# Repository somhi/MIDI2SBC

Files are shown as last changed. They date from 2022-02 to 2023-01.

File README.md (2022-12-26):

# MIDI I2S SBC Pmod Edge Interface

STATUS (26/12/22): Finished gerber files for v1.10. See changelog for updates from v0.7 to v1.1

STATUS (24/03/22): Finished most of testing satisfactorily. 

STATUS (24/03/22): received pcbs (16/03/22) and started testing.  

STATUS (01/03/22): sent v0.70 to manufacturing at JLCPCB

### Intro

This board was born as an addon for [NeptUNO](https://github.com/neptuno-fpga/Main_nepUNO/wiki) FPGA platform (although it can be linked to other FPGAs) for interfacing with a MIDI synthesizer (mt32-pi), DAC I2S, single board computers (or microcontrollers) and pmod peripherals.

This is my first PCB design attempt. 

Project has been developed with KiCAD 6.0.

This design is based on the Eagle design of the RTC+I2S+PIzero Addon by [Antonio Villena](https://www.antoniovillena.es/store/). I have to thank Antonio for his help.

### Flow diagram

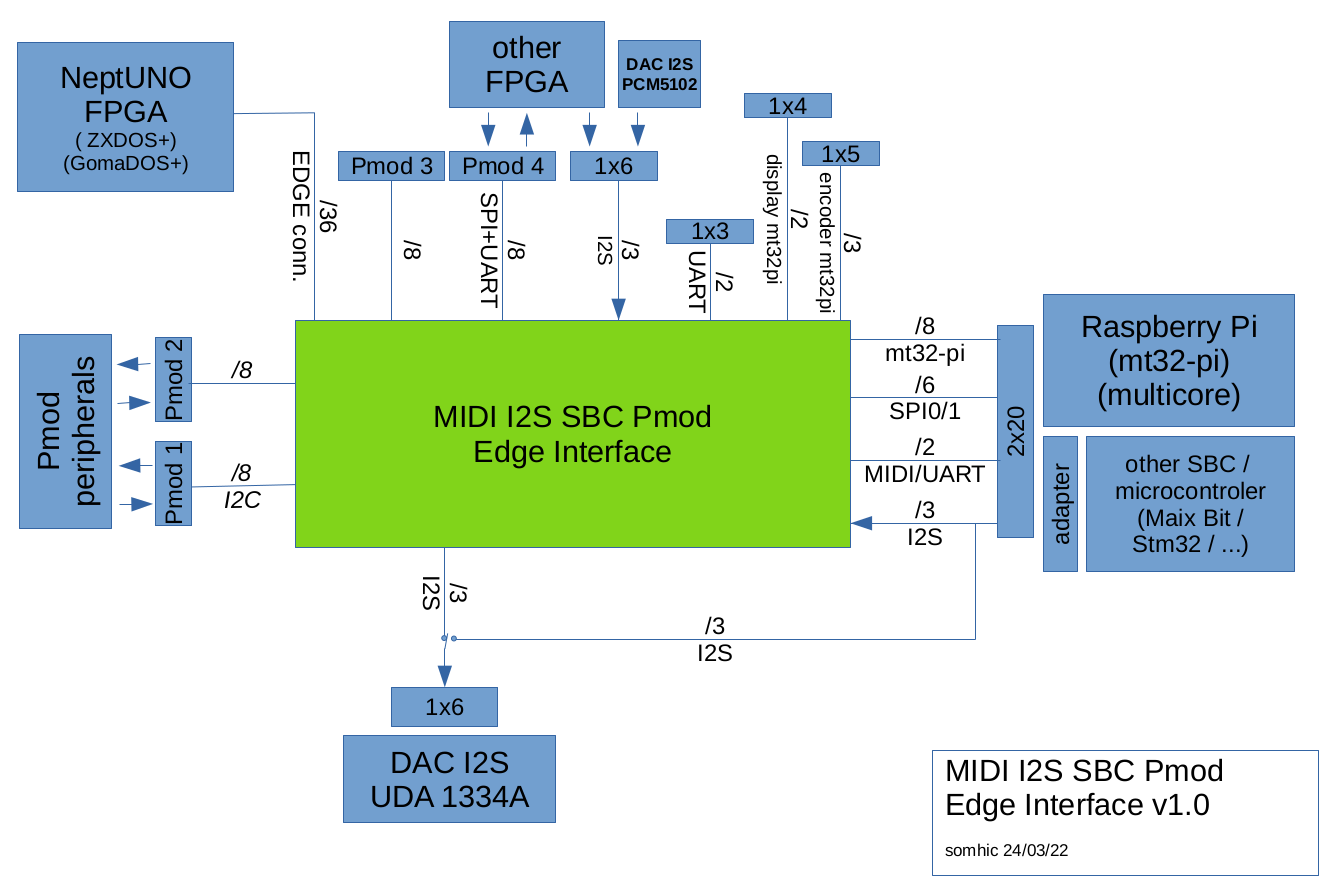
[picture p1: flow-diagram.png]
flow-diagram


### **Schematic**

[addon-edge-rpi-i2s-pmod.pdf](addon-edge-rpi-i2s-pmod.pdf)

### **Features**

* MIDI synthesizer: [mt32-pi](https://github.com/dwhinham/mt32-pi) 
  
  * Play MIDI sounds from FPGA core through an I2S DAC
  * It is possible to send mt32-pi I2S audio back to FPGA for mixing with other core audio and play it back through the I2S DAC
  * PCB includes footprints for an I2C OLED display, a rotative encoder and 2 buttons
  * Control mt32-pi through i2c pins (e.g. from MiSTer's OSD)
  
* DAC I2S: 
  
  * Play I2S audio sent from your FPGA (connected to Edge or Pmod 4)
  * Play I2S audio from Raspberry mt32-pi
  * PCB includes footprints for UDA 1334A and PCM5102A
  
* SBC / Micro-controller interface (Multicore)
  * Interface to FPGAs through Edge or Pmod 4 connectors
  * Interface signals: SPI (6 signals) and UART (Rx/Tx) 
  * PCB includes footprint for Raspberry Pi model B 40 pin connector. Other SBCs or microcontrollers can be interfaced through adapters (e.g. MAix BiT and STM32 adapters are available in [Atlas FPGA project](https://github.com/atlasfpga))
  * A SBC or uC could be used as a multicore device for the FPGA
  
* UART header connected to FPGA (Rx, Tx) (and Raspberry Pi also)

**Additional features for the Edge connector ** 

* Compatible platforms: NeptUNO, ZXDOS+ and GomaDOS+ from [Antonio Villena](https://www.antoniovillena.es/store/). 
  * NeptUNO base board is compatible with most of QMTech FPGAs
* PMODs 1 & 2 for double Pmod peripherals (like Hyperram, VGA, HDMI, ....)
  * Pmod 1 is connected to I2C lines of NeptUNO base board
  * Includes a 5V power supply header between Pmods  for broader compatibility
* PMODs 3 & 4  
  * Can be used as host or peripheral pmods (jumper JP5 enables output power). 
  * Includes a 5V power supply pin between Pmods  for broader compatibility
  * Notes:
    * Double Pmod for peripherals is only possible if not using mt32-pi or multicore options
    * Pmod 3 cannot be used with NeptUNO board cores usign SRAM

### 3D model

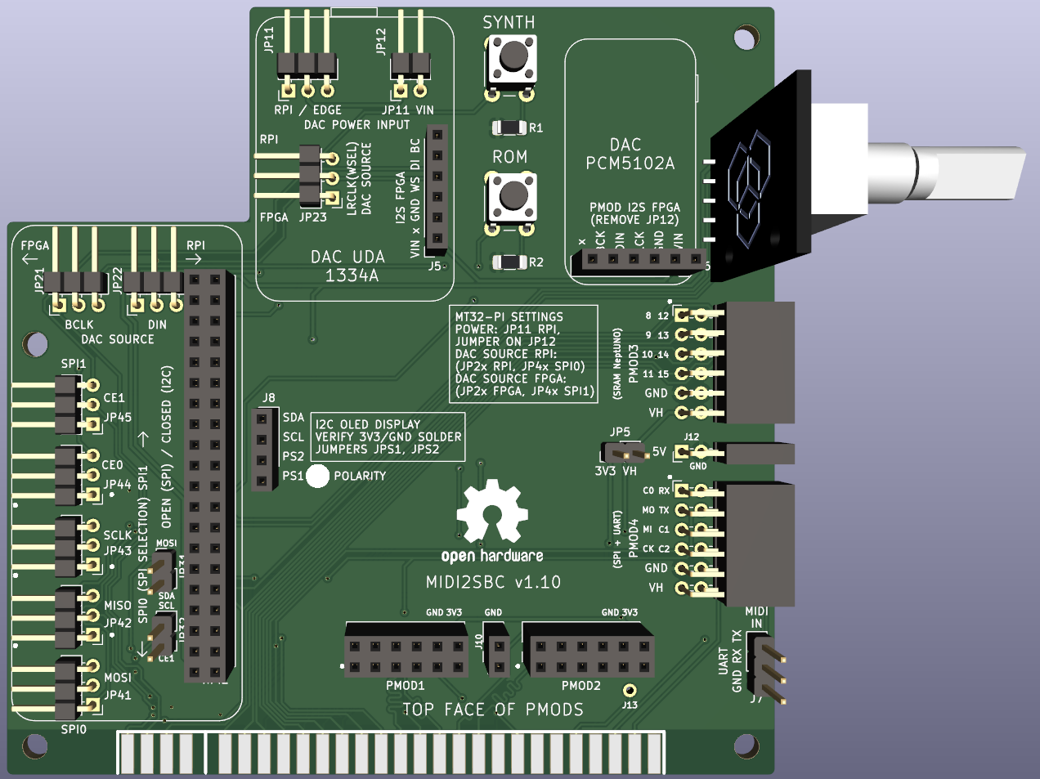
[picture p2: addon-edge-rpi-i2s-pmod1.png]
addon-edge-rpi-i2s-pmod1


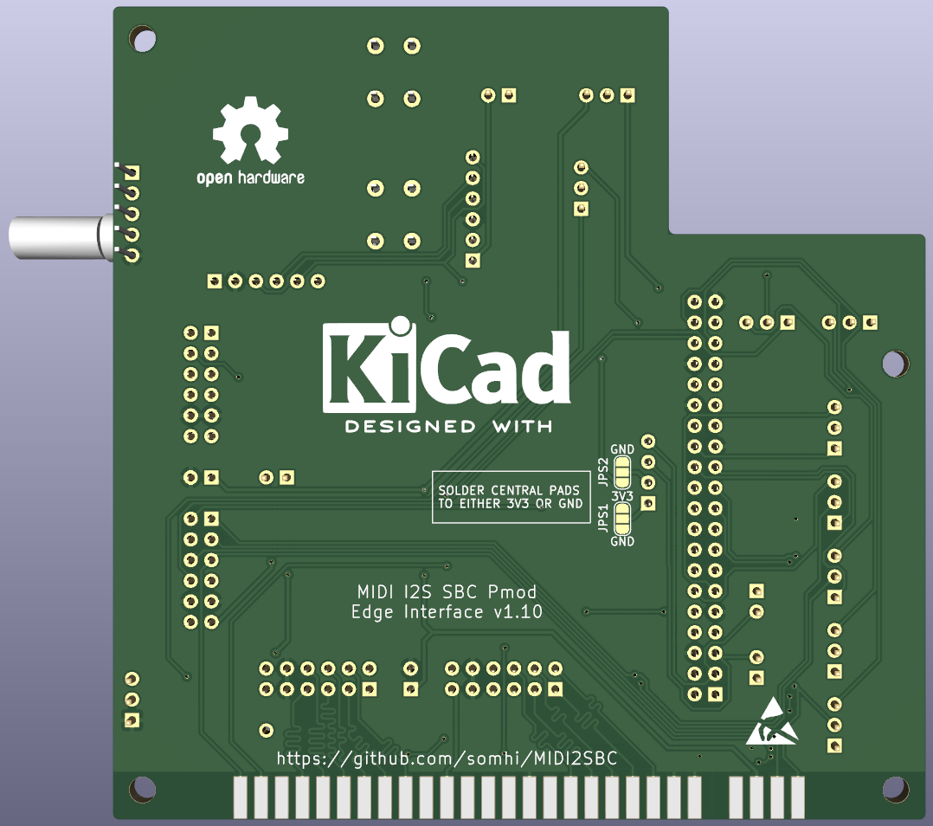
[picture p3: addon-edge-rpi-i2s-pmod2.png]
addon-edge-rpi-i2s-pmod2


### **Usage notes**

* It is recommended to power supply first the FPGA and thereafter the MISI2SBC addon
  
* DAC I2S 
  
  * Only one DAC (either UDA 1334A or PCM5102A) is intended to be used at the same time, although should be possible to run them simultaneously.
  * DAC input voltage can be selected by jumpers from Edge, Raspberry Pi or other FPGA
  * PCM5102A connector is compatible with a 6 pin Pmod if JP11 jumper is removed.
  
* SPI communication between Raspberry Pi and FPGA
  * SPI 0 or SPI 1 is available (selection by jumpers JP4x) 
  * External FPGAs are to be connected to Pmod4 (SPI + UART)

* mt32-pi synthesizer
  * Power supply: JP11 set to RPI and short JP12 with a jumper
  * DAC source from FPGA: SPI 1 should be selected when using mt32-pi (jumpers JP4x)
  * DAC source from RPi: No jumper or SPI 0 should be selected when using mt32-pi (jumpers JP4x)
  * External FPGAs are to be connected to Pmod I2S (PCM5102A) and MIDI In (UART) or Pmod4 (SPI + UART) for mixing.
  * MiSTer OSD i2c control: short jumpers JP31, JP32 and remove jumpers from JP41, JP45.

### **Jumpers / Switches selection**

The board has several jumpers for a broader usage with multiple configurations. Instead of right angle pin headers with jumpers is also possible to use 3 pin mini switches.

**Jumper types**

* 2 pin jumper is either shorted (jumper on) or disconnected (without jumper)

* 3 pin jumper is either on one side or the other always connecting the central pin

**Jumper selection**

* DAC I2S Power supply input source  

  * JP11:  RPI / EDGE   (3 pin jumper)
    * RPI (5V from Raspberry Pi)
    * EDGE (5V from Edge connector (NeptUNO FPGA))
  * JP12  (2 pin jumper)

    * Jumper shorting JP11 and VIN (5V from selection of JP11 jumper is applied to VIN)
    * Without jumper (DAC power input comes from any VIN pin (J4, J5 or J12 Vin itself))

* DAC I2S Audio Source (3 pin jumper)
  * DAC I2S connected to FPGA: I2S sound from MIDI synthesizer mt32-pi (MIDI_CLKBD, MIDI_WSBD, MIDI_DABD signals) is routed to the FPGA (where could be mixed with other core sounds) and the FPGA sends the I2S signals back to the DAC I2S (BCLK, WSEL, DIN signals).
    * JP21, JP22, JP23 jumper connected to the FPGA mark side
  * DAC I2S connected directly to the MIDI synthesizer (mt32-pi)
    * JP21, JP22, JP23   jumper connected to the RPI mark side

* SPI / I2C selection  (2 pin jumpers)

  * SPI selection: JP31 and JP32 open.
  * I2C selection: JP31 and JP32 closed (central pins of MOSI JP41 and CE1 JP45 are wired to the I2C bus connected to the mt32-pi (RPi). Jumpers JP41 and JP45 should be removed to avoid interferences).

* SPI selection: SPI0 or SPI1 (3 pin jumper)

  * SPI0: JP41, JP42, JP43, JP44, JP45  jumper connected to the SPI0 mark side
  * SPI1: JP41, JP42, JP43, JP44, JP45  jumper connected to the SPI1 mark side

* Power supply selection for pins 1 and 2 of the I2C OLED display

  * You might find in the marked I2C displays that need 3V3 on pin 1 and GND on pin 2 whereas others those pins are exchanged

  * JPS1 is a 3 pad solder jumper

    * Solder central pad to either 3V3 or GND for selecting function of PS1 display pin 1

  * JPS2 is a 3 pad solder jumper

    * Solder central pad to either 3V3 or GND for selecting function of PS2 display pin 2

* Power supply for PMOD3 & PMOD4 ( JP5 2 pin jumper )

  * Use as Peripheral pmods: JP5 opened  (No voltage is supplied into VH pins)
  * Use as Host pmods: JP5 closed (3V3 voltage from board is wired into VH pins)

### Notes regarding NeptUNO base board

* Following shared pins of Pmod 1 will only work with slow signals because they are connected to the I2C circuit of the VGA monitor. 

```
PMOD1_D2   I2C SCL    RTC,   VGA  
PMOD1_D3   I2C SDA    RTC,   VGA  
```

A simple way to solve this is to remove pins 12 and 15 with a plier from the VGA connector of the extension cable to the monitor as shown in the following picture:

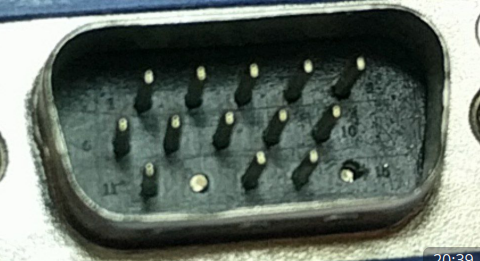
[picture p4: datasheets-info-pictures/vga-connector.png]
vga-connector


* In order to use PMOD1_D5 pin it is required to configure in Quartus as following (Device and Pin Options : Dual-Purpose Pins: nCEO : Use as regular I/O)

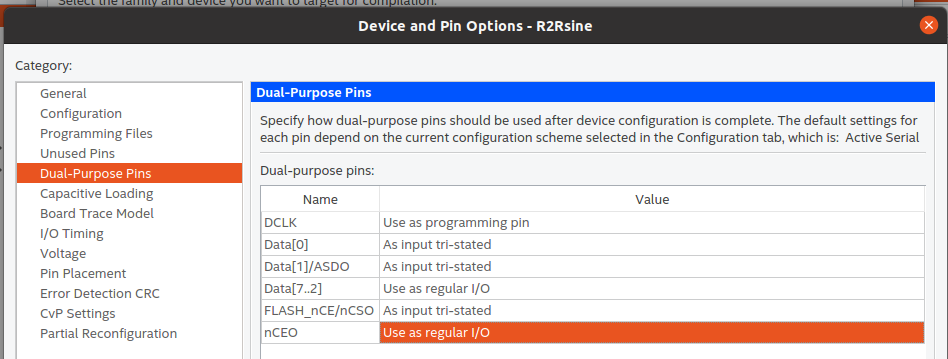
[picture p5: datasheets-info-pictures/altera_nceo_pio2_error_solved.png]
altera_nceo_pio2_error_solved
   

* B24 Edge pin is connected in NeptUNO board internally to the Joy Select signal by means of a solder pad which by default is not soldered. To get this signal in the addon it is required to solder the two pads of the left as seen in the following picture.

  Please notice that it is better not to use the Joy Select pin if you intend the use also pin 7 on DB9 connectors of NeptUNO board for the joy select function of Sega megadrive joysticks.

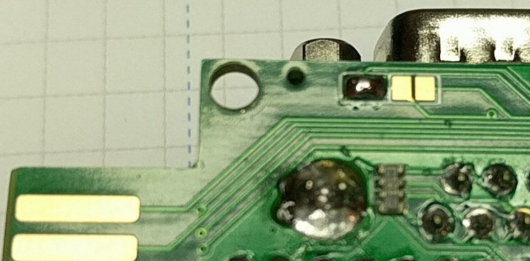
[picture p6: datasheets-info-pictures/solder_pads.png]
solder-pads
  

### Changelog

v0.42  last version with 25 pins

v0.50  added 10 more pins connected at Edge connector to FPGA. Those pins are shared with other peripherals (2 pins bus I2C shared with RTC and VGA connector, 8 pins shared with SRAM memory)

v0.60  routed and gerber done

**v0.70** minor changes. Prototype version sent to manufacturing

v0.71 corrected minor misalignment between Pmod 1 and Pmod 2

v0.72 silkscreen updated (midi and mt32pi settings)

v1.00 silkscreen and documentation improved. Pmod3 and Pmod4 silkscreen labels exchanged. Rounded corners of outline. Pmod3/4 moved 0.4 mm outside.

v1.01 silkscreen for pmod i2s (PCM5102A connector). Improved usage notes in readme.

v1.02 minor silkscreen changes, usage notes.

v1.05 minor silkscreen changes

v1.10 routed i2c pins to PMOD 4 to communicate Raspberry Pi and FPGA (e.g. MiSTer can control mt32-pi from OSD)

### **Todo / Improvements**

* Mechanical stability of i2S DACs and display could be improved. -> Solution: bending a little bit the pins from the display and the DAC I2S so they fix better to the board sockets and don't move.

* Add in the same PCB a breokout board for converting PMO4 to USB3 for MiSTer connection

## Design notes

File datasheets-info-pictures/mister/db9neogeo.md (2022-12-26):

Javier, [23/11/22 11:30]
lo único que no coincide es el tema de la alimentación, será porque tengo una revisión más reciente que incorpora el conversor DC-DC de 5v a 3.3v

Javier, [23/11/22 11:30]
entonces la alimentación va por el pin 1 VBUS

Javier, [23/11/22 11:31]
recibe 5v de alimentación y la señalización funciona a 3.3v

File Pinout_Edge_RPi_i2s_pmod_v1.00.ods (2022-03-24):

Pinouts_Edge_Rpi_i2s_pmod v1.00
KICAD net | FPGA CONNECTIONS |  |  |  |  |  |  |  |  |  |  |  |  | RASPBERRY PI CONNECTIONS
 | 2x28 |  |  |  | 2x20 |  |  | 2x6 | 2x6 | 1x6 | 1x6 | 1x3 | 1x1 | Jumpers | 1x4 | 1x5
 | EDGE NEPTUNO |  |  |  | RASPBERRY PI |  |  | DOUBLE | DOUBLE | FOOTPRINT | FOOTPRINT | HEADER | PAD | Mt32Pi > 1334A | HEADER | HEADER
 | EDGE signal | EDGE PIN | EP4CE55 PIN | SHARED SIGNALS | PIN (GPIO) | mt32Pi | MultiCore | PMOD 1, 2 | PMOD 3, 4 | DAC 1334A (or I2S FPGA) | PCM5102A (or I2S FPGA) | UART FPGA | joy select | Mt32Pi > PCM5102 | DISPLAY I2C | ENCODER
 |  |  |  |  |  |  |  |  |  | mixed sound | mixed sound | also Rpi |  | sound not mixed
 | VDD 3V3 | A18 |  |  |  |  |  | 3V3 | 3V3 / x
 | 5V | A3 |  |  |  |  |  | 5V | 5V | VIN pin1 (JP11/12) | VIN (JP11/12)
 | GND 1,2,3 | A6/7/14 |  |  | 6,9,14,20,25,30,34,39 (GND) |  |  | GND | GND | GND pin3 | GND | GND |  |  | GND/3V3 (JPS1) | GND
 |  |  |  |  | 2,4 (5V) |  |  |  |  | VIN pin1 (JP11/12) | VIN (JP11/12)
 |  |  |  |  | 1,17 (3V3) |  |  |  |  |  |  |  |  |  | 3V3/GND (JPS2) | 3V3
B16_UART_TX_MIDI | MREQ | B16 | PIN_U22 | MIDI_OUT | 10 (GPIO15) (UART RX) | MIDI_OUT | UART TX |  | PMOD4_D5 |  |  | UART TX
B14_CE0_CLKBD | NMI | B14 | PIN_P22 | MIDI_CLKBD | 12 (GPIO18) (SPI1 CE0) | MIDI_CLKBD | SPI1 CE0 (JP44) |  | PMOD4_D0 |  |  |  |  | (mt32-pi) CLKBD (JP21)
 | NMI | B14 | PIN_P22 |  | 24 (GPIO08) (SPI0 CE0) |  | SPI0 CE0 (JP44) |  |  |  |  |  |  | or
B2_BCLK_I2S | A13 | B2 | PIN_M20 | BCLK |  |  |  |  |  | (SCLK) BCLK pin6 | BCLK |  |  | (FPGA) BCLK (JP21)
A28_MISO_WSBD | A11 | A28 | PIN_AA14 | MIDI_WSBD | 35 (GPIO19) (SPI1 MISO) | MIDI_WSBD | SPI1 MISO (JP42) |  | PMOD4_D2 |  |  |  |  | (mt32-pi) WSBD (JP23)
 | A11 | A28 | PIN_AA14 |  | 21 (GPIO09) (SPI0 MISO) |  | SPI0 MISO (JP42) |  |  |  |  |  |  | or
B26_WSEL_LRCLK_I2S | A8 | B26 | PIN_AB14 | LRCLK |  |  |  |  |  | (LRCLK) WSEL pin4 | LRCK |  |  | (FPGA) WSEL (JP23)
B13_SCLK_DABD | INT | B13 | PIN_N22 | MIDI_DABD | 40 (GPIO21) (SPI1 SCLK) | MIDI_DABD | SPI1 SCLK (JP43) |  | PMOD4_D3 |  |  |  |  | (mt32-pi) DABD (JP22)
 | INT | B13 | PIN_N22 |  | 23 (GPIO11) (SPI0 SCLK) |  | SPI0 SCLK (JP43) |  |  |  |  |  |  | or
A27_DIN_I2S | A9 | A27 | PIN_AA15 | DIN |  |  |  |  |  | (SDIN) DIN pin5 | DIN |  |  | (FPGA) DIN (JP22)
A1_MOSI | A14 | A1 | PIN_B22 |  | 38 (GPIO20) (SPI1 MOSI) |  | SPI1 MOSI (JP41) |  | PMOD4_D1
 | A14 | A1 | PIN_B22 |  | 19 (GPIO10) (SPI0 MOSI) |  | SPI0 MOSI (JP41)
A2_CE1 | A12 | A2 | PIN_C22 |  | 11 (GPIO17) (SPI1 CE1) | (BUTTON 1 mt32pi) | SPI1 CE1 (JP45) |  | PMOD4_D6
 | A12 | A2 | PIN_C22 |  | 26 (GPIO07) (SPI0 CE1) |  | SPI0 CE1 (JP45)
B1_UART_RX | A15 | B1 | PIN_M19 |  | 8 (GPIO14) (UART TX) |  | UART RX |  | PMOD4_D4 |  |  | UART RX
B27_SPI1CE2 | A10 | B27 | PIN_AB13 |  | 36 (GPIO16) (SPI1 CE2) |  | SPI1 CE2 |  | PMOD4_D7
A9_PMOD1_D0 | A0 | A9 | PIN_K21 | (STM_A10 – RX) |  |  |  | PMOD1_D0
A11_PMOD1_D1 | A2 | A11 | PIN_M21 | (STM_B14 – MISO) |  |  |  | PMOD1_D1
B15_SCL_PM1_D2 | HALT | B15 | PIN_R22 | I2C SCL RTC, VGA | this shared pin with the VGA connector causes slowliness (see readme) |  |  | PMOD1_D2
B21_SDA_PM1_D3 | WAIT | B21 | PIN_V21 | I2C SDA RTC, VGA | this shared pin with the VGA connector causes slowliness (see readme) |  |  | PMOD1_D3
A8_PMOD1_D4 | CLK | A8 | PIN_J21 | (STM_A9 – TX) |  |  |  | PMOD1_D4
A10_PMOD1_D5 | A1 | A10 | PIN_K22 | (STM_B15 – MOSI), ALTERA_nCEO (see readme for configuring this pin as regular I/O) |  |  |  | PMOD1_D5
A12_PMOD1_D6 | A3 | A12 | PIN_N21 | (STM_B13 – SCK) |  |  |  | PMOD1_D6
B17_PMOD1_D7 | IORQ | B17 | PIN_W21 |  |  |  |  | PMOD1_D7
B19_PMOD2_D0 | WR | B19 | PIN_W22 |  |  |  |  | PMOD2_D0
A21_PMOD2_D1 | A7 | A21 | PIN_AB19 |  |  |  |  | PMOD2_D1
A23_PMOD2_D2 | A5 | A23 | PIN_AA19 |  |  |  |  | PMOD2_D2
A25_PMOD2_D3 | ROMCS | A25 | PIN_AA17 |  |  |  |  | PMOD2_D3
B18_PMOD2_D4 | RD | B18 | PIN_V22 |  |  |  |  | PMOD2_D4
A20_PMOD2_D5 | RESET | A20 | PIN_Y22 |  |  |  |  | PMOD2_D5
A22_PMOD2_D6 | A6 | A22 | PIN_AB18 |  |  |  |  | PMOD2_D6
A24_PMOD2_D7 | A4 | A24 | PIN_AB17 |  |  |  |  | PMOD2_D7
B6_SRAMDQ8 | D0 | B6 | PIN_F22 | SRAM_DQ[8] |  |  |  |  | PMOD3_D0
B7_SRAMDQ9 | D1 | B7 | PIN_H21 | SRAM_DQ[9] |  |  |  |  | PMOD3_D1
B8_SRAMDQ10 | D2 | B8 | PIN_H22 | SRAM_DQ[10] |  |  |  |  | PMOD3_D2
B11_SRAMDQ11 | D3 | B11 | PIN_L22 | SRAM_DQ[11] |  |  |  |  | PMOD3_D3
B12_SRAMDQ12 | D4 | B12 | PIN_M22 | SRAM_DQ[12] |  |  |  |  | PMOD3_D4
B10_SRAMDQ13 | D5 | B10 | PIN_L21 | SRAM_DQ[13] |  |  |  |  | PMOD3_D5
B9_SRAMDQ14 | D6 | B9 | PIN_J22 | SRAM_DQ[14] |  |  |  |  | PMOD3_D6
B3_SRAMDQ15 | D7 | B3 | PIN_F21 | SRAM_DQ[15] |  |  |  |  | PMOD3_D7
B24_JOY_SEL | M1 | B24 | PIN_AA18 | JOY SELECT | JOY SELECT (DO NOT USE THIS PIN ON NEPTUNO FPGA AS MOST CORES MAKE USE OF THIS SIGNAL) |  |  |  |  |  |  |  | J13
 |  |  |  |  | In order to use B24_JOY_SEL it is required to solder two pads on the NeptUNO board (see readme)
 |  |  |  |  | 3 (GPIO02) |  |  |  |  |  |  |  |  |  | SDA_RPI
 |  |  |  |  | 5 (GPIO03) |  |  |  |  |  |  |  |  |  | SCL_RPI
 |  |  |  |  | 7 (GPIO04) |  |  |  |  |  |  |  |  |  |  | PIMIDI_BUT5
 |  |  |  |  | 13 (GPIO27) | PIMIDI_BUT2
 |  |  |  |  | 15 (GPIO22) |  |  |  |  |  |  |  |  |  |  | PIMIDI_B3_CLK
 |  |  |  |  | 16 (GPIO23) |  |  |  |  |  |  |  |  |  |  | PIMIDI_B4_DAT
 |  |  |  |  | 18 (GPIO24)
 |  |  |  |  | 22 (GPIO25)
 |  |  |  |  | 27 (GPIO00)
 |  |  |  |  | 28 (GPIO01)
 |  |  |  |  | 29 (GPIO05)
 |  |  |  |  | 31 (GPIO06)
 |  |  |  |  | 32 (GPIO12)
 |  |  |  |  | 33 (GPIO13)
 |  |  |  |  | 37 (GPIO26)
JUMPERS: |  |  |  |  |  |  | Information mt32-pi:
Jumpers 1: power supply source for DAC I2S: 5V from RPI or EDGE connector, or 5V/3V3 from external FPGA or power supply |  |  |  |  |  |  | https://github.com/dwhinham/mt32-pi/wiki/LCD-and-OLED-displays
Jumpers 2: I2S source for DAC: from mt32-pi or from FPGA |  |  |  |  |  |  | https://github.com/dwhinham/mt32-pi/wiki/Control-surface
Jumpers 4: selection of SPI interface (SPI0 / SPI1)
JPS1, JPS2 are to select 3V3 and GND for pins 1, 2 of I2C OLED display
Notes:
EDGE A is bottom face of Neptuno board. B is Top face of Neptuno board.
(SCLK), (CLKBD), … are Next186 NeptUNO signals

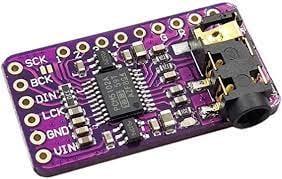
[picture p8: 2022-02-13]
datasheets-info-pictures/PCM5102-2.jpg

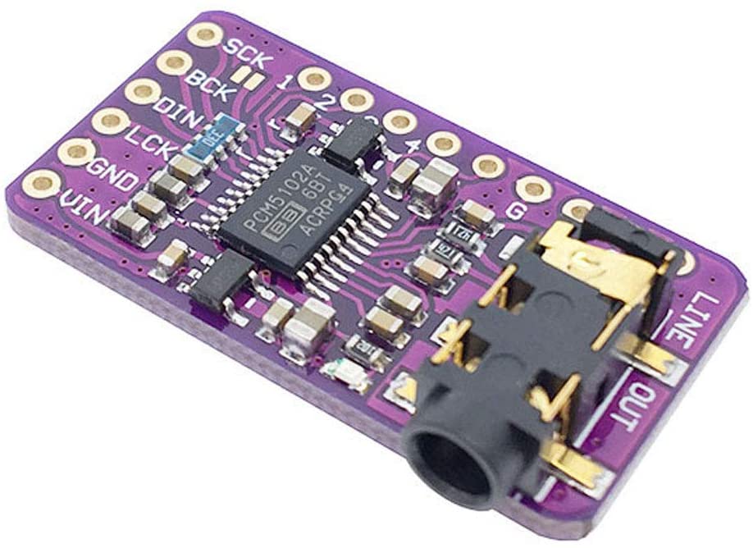
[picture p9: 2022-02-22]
datasheets-info-pictures/PCM5102-3.jpg

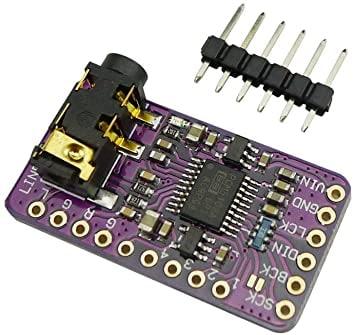
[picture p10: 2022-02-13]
datasheets-info-pictures/PCM5102-1.jpg

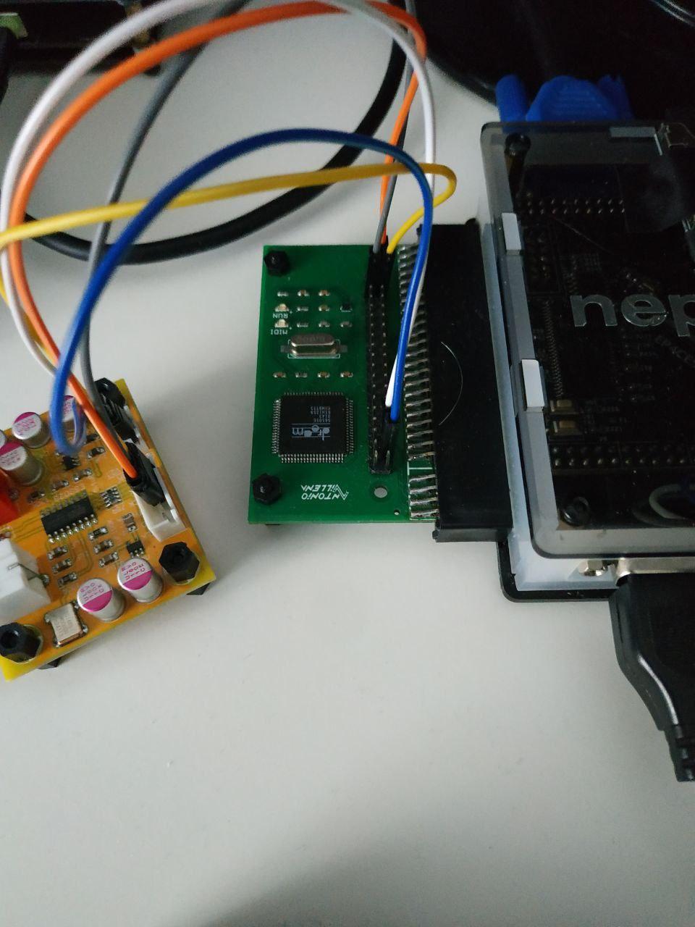
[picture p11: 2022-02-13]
datasheets-info-pictures/neptuno-i2s-RTC-addon.jpg

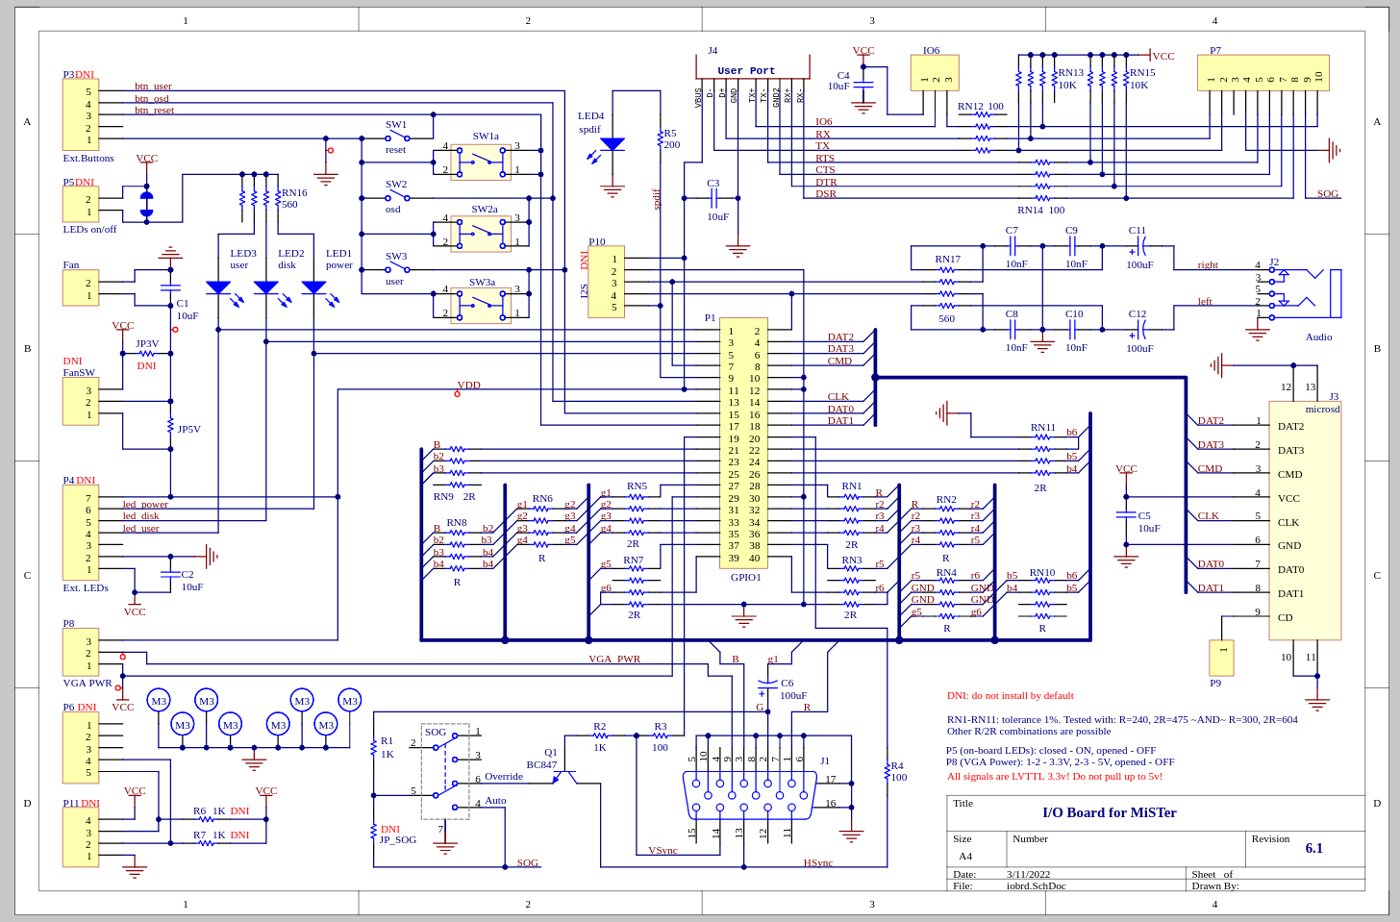
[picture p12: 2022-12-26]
datasheets-info-pictures/mister/IO_board_for_MiSTer_r6.1.png

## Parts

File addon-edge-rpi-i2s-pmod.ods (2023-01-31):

Source: | /home/jordi/Kicad/a_Neptuno/MIDI_I2S_SBC_Pmod_Edge_Interface_GITHUB/addon-edge-rpi-i2s-pmod.kicad_sch
Date: | Wed 16 Mar 2022 23:13:06 CET
Tool: | Eeschema 6.0.0-d3dd2cf0fa~116~ubuntu20.04.1
Generator: | /usr/share/kicad/plugins/bom_csv_grouped_by_value.py
Component Count: | 35
Individual Components:
Item | Qty | Reference(s) |  | Value | LibPart | Footprint | Datasheet
 |  | BUT1 |  | SW_DIP_x01 | Switch:SW_DIP_x01 | Button_Switch_THT:SW_PUSH_6mm_H5mm | ~
 |  | BUT2 |  | SW_DIP_x01 | Switch:SW_DIP_x01 | Button_Switch_THT:SW_PUSH_6mm_H5mm | ~
 |  | EDGE1 |  | ZXSP_ED2X28_SPE_SOL_EDGE | gomaDOSzero-eagle-import:ZXSP_ED2X28_SPE_SOL_EDGE | gomaDOSzero:2X28_SPE2
 |  | H1 |  | MountingHole | Mechanical:MountingHole | MountingHole:MountingHole_3.2mm_M3 | ~
 |  | H2 |  | MountingHole | Mechanical:MountingHole | MountingHole:MountingHole_3.2mm_M3 | ~
 |  | H3 |  | MountingHole | Mechanical:MountingHole | MountingHole:MountingHole_3.2mm_M3 | ~
 |  | H4 |  | MountingHole | Mechanical:MountingHole | MountingHole:MountingHole_3.2mm_M3 | ~
 |  | J1 |  | PMOD1 | Connector_Generic:Conn_02x06_Top_Bottom | gomaDOSzero:Pmod_2x06_P2.54mm_Vertical_2 | ~
 |  | J2 |  | PMOD2 | Connector_Generic:Conn_02x06_Top_Bottom | gomaDOSzero:Pmod_2x06_P2.54mm_Vertical_2 | ~
 |  | J3 |  | PMOD3 | Connector_Generic:Conn_02x06_Top_Bottom | gomaDOSzero:PMOD_Female_Horizontal_2 | ~
 |  | J4 |  | PMOD4 | Connector_Generic:Conn_02x06_Top_Bottom | gomaDOSzero:PMOD_Female_Horizontal_2 | ~
 |  | J5 |  | Conn_01x06 | Connector_Generic:Conn_01x06 | gomaDOSzero:UDA1334 | ~
 |  | J6 |  | Conn_01x06 | Connector_Generic:Conn_01x06 | gomaDOSzero:PCM5102 | ~
 |  | J7 |  | Conn_01x03 | Connector_Generic:Conn_01x03 | Connector_PinHeader_2.54mm:PinHeader_1x03_P2.54mm_Vertical | ~
 |  | J8 |  | Conn_01x04 | Connector_Generic:Conn_01x04 | gomaDOSzero:I2C_DISPLAY_MULTI2 | ~
 |  | J9 |  | Conn_01x05 | Connector_Generic:Conn_01x05 | Connector_PinSocket_2.54mm:PinSocket_1x05_P2.54mm_Vertical | ~
 |  | J10 |  | Conn_01x02 | Connector_Generic:Conn_01x02 | Connector_PinSocket_2.54mm:PinSocket_1x02_P2.54mm_Vertical | ~
 |  | J12 |  | Conn_01x02 | Connector_Generic:Conn_01x02 | Connector_PinSocket_2.54mm:PinSocket_2x01_P2.54mm_Horizontal | ~
 |  | J13 |  | Conn_01x01 | Connector_Generic:Conn_01x01 | Connector_PinHeader_2.54mm:PinHeader_1x01_P2.54mm_Vertical | ~
 |  | JP5 |  | Conn_01x02 | Connector_Generic:Conn_01x02 | Connector_PinHeader_2.54mm:PinHeader_1x02_P2.54mm_Vertical | ~
 |  | JP11 |  | Conn_01x03 | Connector_Generic:Conn_01x03 | Connector_PinHeader_2.54mm:PinHeader_1x03_P2.54mm_Horizontal | ~
 |  | JP12 |  | Conn_01x02 | Connector_Generic:Conn_01x02 | Connector_PinHeader_2.54mm:PinHeader_1x02_P2.54mm_Horizontal | ~
 |  | JP21 |  | Conn_01x03 | Connector_Generic:Conn_01x03 | Connector_PinHeader_2.54mm:PinHeader_1x03_P2.54mm_Horizontal | ~
 |  | JP22 |  | Conn_01x03 | Connector_Generic:Conn_01x03 | Connector_PinHeader_2.54mm:PinHeader_1x03_P2.54mm_Horizontal | ~
 |  | JP23 |  | Conn_01x03 | Connector_Generic:Conn_01x03 | Connector_PinHeader_2.54mm:PinHeader_1x03_P2.54mm_Horizontal | ~
 |  | JP41 |  | Conn_01x03 | Connector_Generic:Conn_01x03 | Connector_PinHeader_2.54mm:PinHeader_1x03_P2.54mm_Horizontal | ~
 |  | JP42 |  | Conn_01x03 | Connector_Generic:Conn_01x03 | Connector_PinHeader_2.54mm:PinHeader_1x03_P2.54mm_Horizontal | ~
 |  | JP43 |  | Conn_01x03 | Connector_Generic:Conn_01x03 | Connector_PinHeader_2.54mm:PinHeader_1x03_P2.54mm_Horizontal | ~
 |  | JP44 |  | Conn_01x03 | Connector_Generic:Conn_01x03 | Connector_PinHeader_2.54mm:PinHeader_1x03_P2.54mm_Horizontal | ~
 |  | JP45 |  | Conn_01x03 | Connector_Generic:Conn_01x03 | Connector_PinHeader_2.54mm:PinHeader_1x03_P2.54mm_Horizontal | ~
 |  | JPS1 |  | SolderJumper_3_Open | Jumper:SolderJumper_3_Open | Jumper:SolderJumper-3_P1.3mm_Open_RoundedPad1.0x1.5mm_NumberLabels | ~
 |  | JPS2 |  | SolderJumper_3_Open | Jumper:SolderJumper_3_Open | Jumper:SolderJumper-3_P1.3mm_Open_RoundedPad1.0x1.5mm_NumberLabels | ~
 |  | R1 |  | 1k | Device:R | Resistor_SMD:R_1206_3216Metric_Pad1.30x1.75mm_HandSolder | ~
 |  | R2 |  | 1k | Device:R | Resistor_SMD:R_1206_3216Metric_Pad1.30x1.75mm_HandSolder | ~
 |  | RPI1 |  | RASPBERRYPI_BPLUS_BONNETNODIM | gomaDOSzero-eagle-import:RASPBERRYPI_BPLUS_BONNETNODIM | Connector_PinSocket_2.54mm:PinSocket_2x20_P2.54mm_Vertical
Collated Components:
Item | Qty | Reference(s) | notes | Value | LibPart | Footprint | Datasheet
1 | 2 | BUT1, BUT2 | https://es.aliexpress.com/item/1005003938985112.html | SW_DIP_x01 | Switch:SW_DIP_x01 | Button_Switch_THT:SW_PUSH_6mm_H5mm | ~
2 | 1 | EDGE1 | https://es.aliexpress.com/item/1005002212044956.html | ZXSP_ED2X28_SPE_SOL_EDGE | gomaDOSzero-eagle-import:ZXSP_ED2X28_SPE_SOL_EDGE | gomaDOSzero:2X28_SPE2
3 | 4 | H1, H2, H3, H4 | DNI | MountingHole | Mechanical:MountingHole | MountingHole:MountingHole_3.2mm_M3 | ~
4 | 1 | J1 | https://es.aliexpress.com/item/4000706582286.html | PMOD1 | Connector_Generic:Conn_02x06_Top_Bottom | gomaDOSzero:Pmod_2x06_P2.54mm_Vertical_2 | ~
5 | 1 | J2 | https://es.aliexpress.com/item/4000706582286.html | PMOD2 | Connector_Generic:Conn_02x06_Top_Bottom | gomaDOSzero:Pmod_2x06_P2.54mm_Vertical_2 | ~
6 | 1 | J3 | https://es.aliexpress.com/item/32890057619.html | PMOD3 | Connector_Generic:Conn_02x06_Top_Bottom | gomaDOSzero:PMOD_Female_Horizontal_2 | ~
7 | 1 | J4 | https://es.aliexpress.com/item/32890057619.html | PMOD4 | Connector_Generic:Conn_02x06_Top_Bottom | gomaDOSzero:PMOD_Female_Horizontal_2 | ~
8 | 1 | J5 | https://es.aliexpress.com/item/1005001914815306.html | Conn_01x06 | Connector_Generic:Conn_01x06 | gomaDOSzero:UDA1334 | ~
9 | 1 | J6 | https://es.aliexpress.com/item/1005001914815306.html | Conn_01x06 | Connector_Generic:Conn_01x06 | gomaDOSzero:PCM5102 | ~
10 | 1 | J7 | https://es.aliexpress.com/item/32759414721.html | Conn_01x03 | Connector_Generic:Conn_01x03 | Connector_PinHeader_2.54mm:PinHeader_1x03_P2.54mm_Vertical | ~
11 | 1 | J8 | https://es.aliexpress.com/item/1005001914815306.html | Conn_01x04 | Connector_Generic:Conn_01x04 | gomaDOSzero:I2C_DISPLAY_MULTI2 | ~
12 | 1 | J9 | https://es.aliexpress.com/item/1005001453647644.html | Conn_01x05 | Connector_Generic:Conn_01x05 | Connector_PinSocket_2.54mm:PinSocket_1x05_P2.54mm_Vertical | ~
13 | 1 | J10 | https://es.aliexpress.com/item/1005001914815306.html | Conn_01x02 | Connector_Generic:Conn_01x02 | Connector_PinSocket_2.54mm:PinSocket_1x02_P2.54mm_Vertical | ~
14 | 1 | J12 | DNI | Conn_01x02 | Connector_Generic:Conn_01x02 | Connector_PinSocket_2.54mm:PinSocket_2x01_P2.54mm_Horizontal | ~
15 | 1 | J13 | DNI | Conn_01x01 | Connector_Generic:Conn_01x01 | Connector_PinHeader_2.54mm:PinHeader_1x01_P2.54mm_Vertical | ~
16 | 1 | JP5 | https://es.aliexpress.com/item/32759414721.html | Conn_01x02 | Connector_Generic:Conn_01x02 | Connector_PinHeader_2.54mm:PinHeader_1x02_P2.54mm_Vertical | ~
17 | 9 | JP11, JP21, JP22, JP23, JP41, JP42, JP43, JP44, JP45 | https://es.aliexpress.com/item/33009763749.html | Conn_01x03 | Connector_Generic:Conn_01x03 | Connector_PinHeader_2.54mm:PinHeader_1x03_P2.54mm_Horizontal | ~
18 | 1 | JP12 | https://es.aliexpress.com/item/32908642552.html | Conn_01x02 | Connector_Generic:Conn_01x02 | Connector_PinHeader_2.54mm:PinHeader_1x02_P2.54mm_Horizontal | ~
19 | 2 | JPS1, JPS2 | DNI | SolderJumper_3_Open | Jumper:SolderJumper_3_Open | Jumper:SolderJumper-3_P1.3mm_Open_RoundedPad1.0x1.5mm_NumberLabels | ~
20 | 2 | R1, R2 | 1206 SMD 1k | 1k | Device:R | Resistor_SMD:R_1206_3216Metric_Pad1.30x1.75mm_HandSolder | ~
21 | 1 | RPI1 | https://es.aliexpress.com/item/1005003335405213.html | RASPBERRYPI_BPLUS_BONNETNODIM | gomaDOSzero-eagle-import:RASPBERRYPI_BPLUS_BONNETNODIM | Connector_PinSocket_2.54mm:PinSocket_2x20_P2.54mm_Vertical
 |  | JUMPERS | https://es.aliexpress.com/item/10000002338839.html
 |  | PILARS & NUTS

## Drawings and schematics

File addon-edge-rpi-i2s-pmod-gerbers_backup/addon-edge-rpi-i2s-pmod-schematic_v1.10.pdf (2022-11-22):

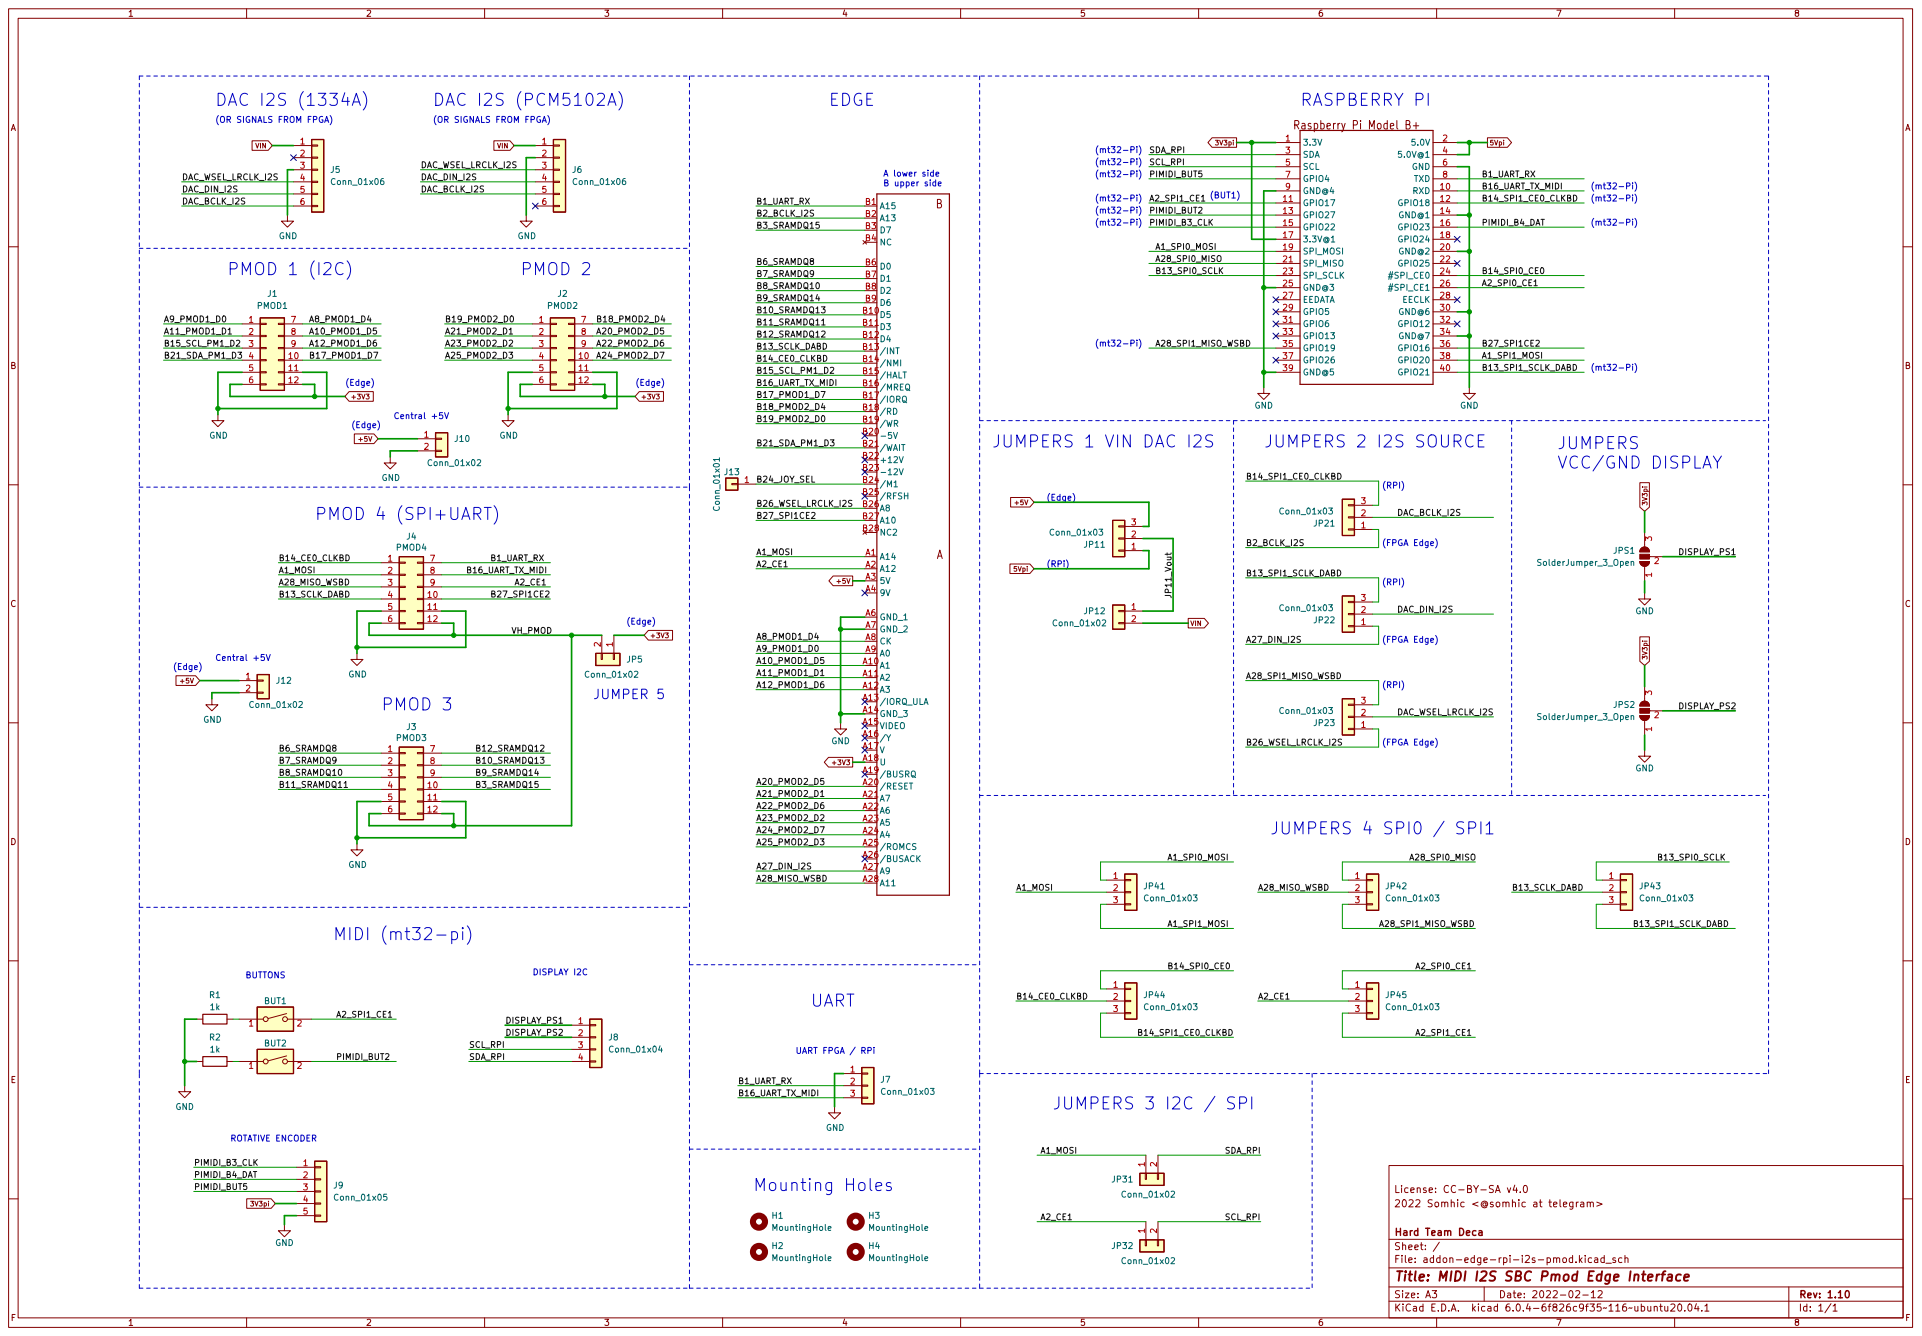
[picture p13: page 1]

(OR SIGNALS FROM FPGA)

(mt32-Pi) A lower side B upper side

JUMPERS 3 I2C / SPI DISPLAY I2C MIDI (mt32-pi)

License: CC-BY-SA v4.0
2022 Somhic <@somhic at telegram>

File: addon-edge-rpi-i2s-pmod.kicad_sch Sheet: / Hard Team Deca

Id: 1/1 Title: MIDI I2S SBC Pmod Edge Interface

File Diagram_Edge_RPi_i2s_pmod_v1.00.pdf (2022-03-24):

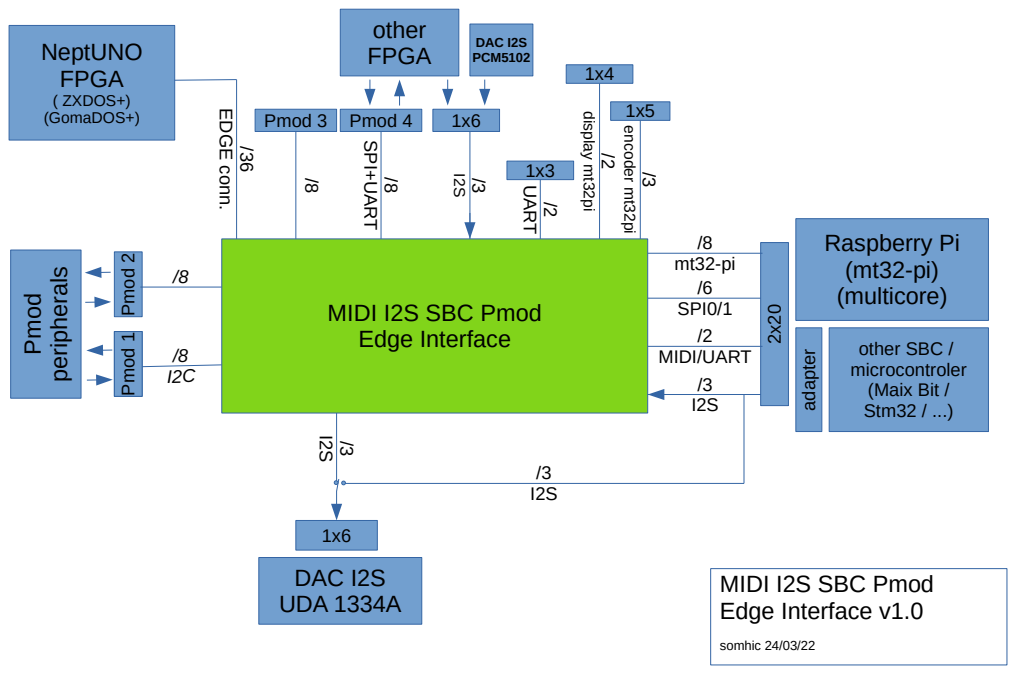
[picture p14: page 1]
Raspberry Pi (mt32-pi) (multicore); DAC I2S UDA 1334A; /6 SPI0/1; NeptUNO FPGA ( ZXDOS+) (GomaDOS+); erip; erals; Pmod 4; other FPGA; dis; pla; somhic 24/03/22; DAC I2S PCM5102; MIDI/UART; other SBC /; microcontroler (Maix Bit / Stm32 / ...) a; pter; Pmod 3

MIDI I2S SBC Pmod
Edge Interface

Edge Interface v1.0

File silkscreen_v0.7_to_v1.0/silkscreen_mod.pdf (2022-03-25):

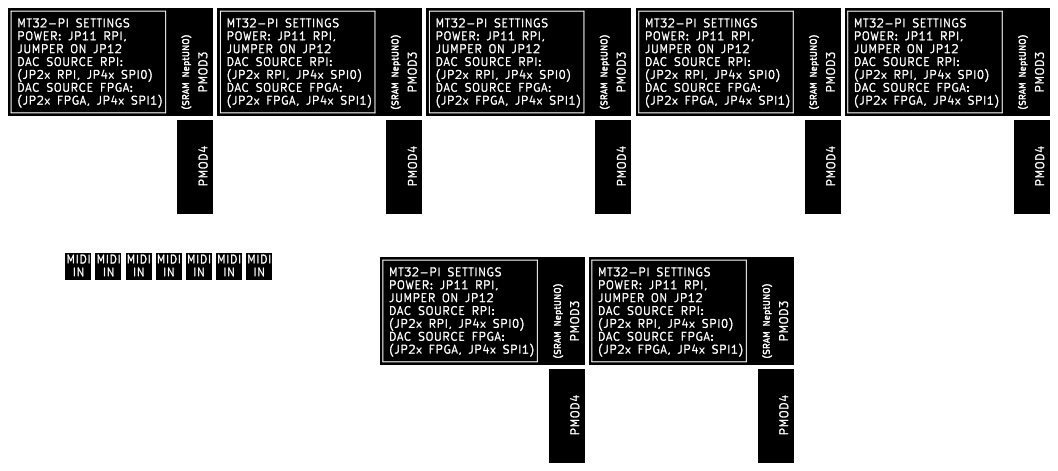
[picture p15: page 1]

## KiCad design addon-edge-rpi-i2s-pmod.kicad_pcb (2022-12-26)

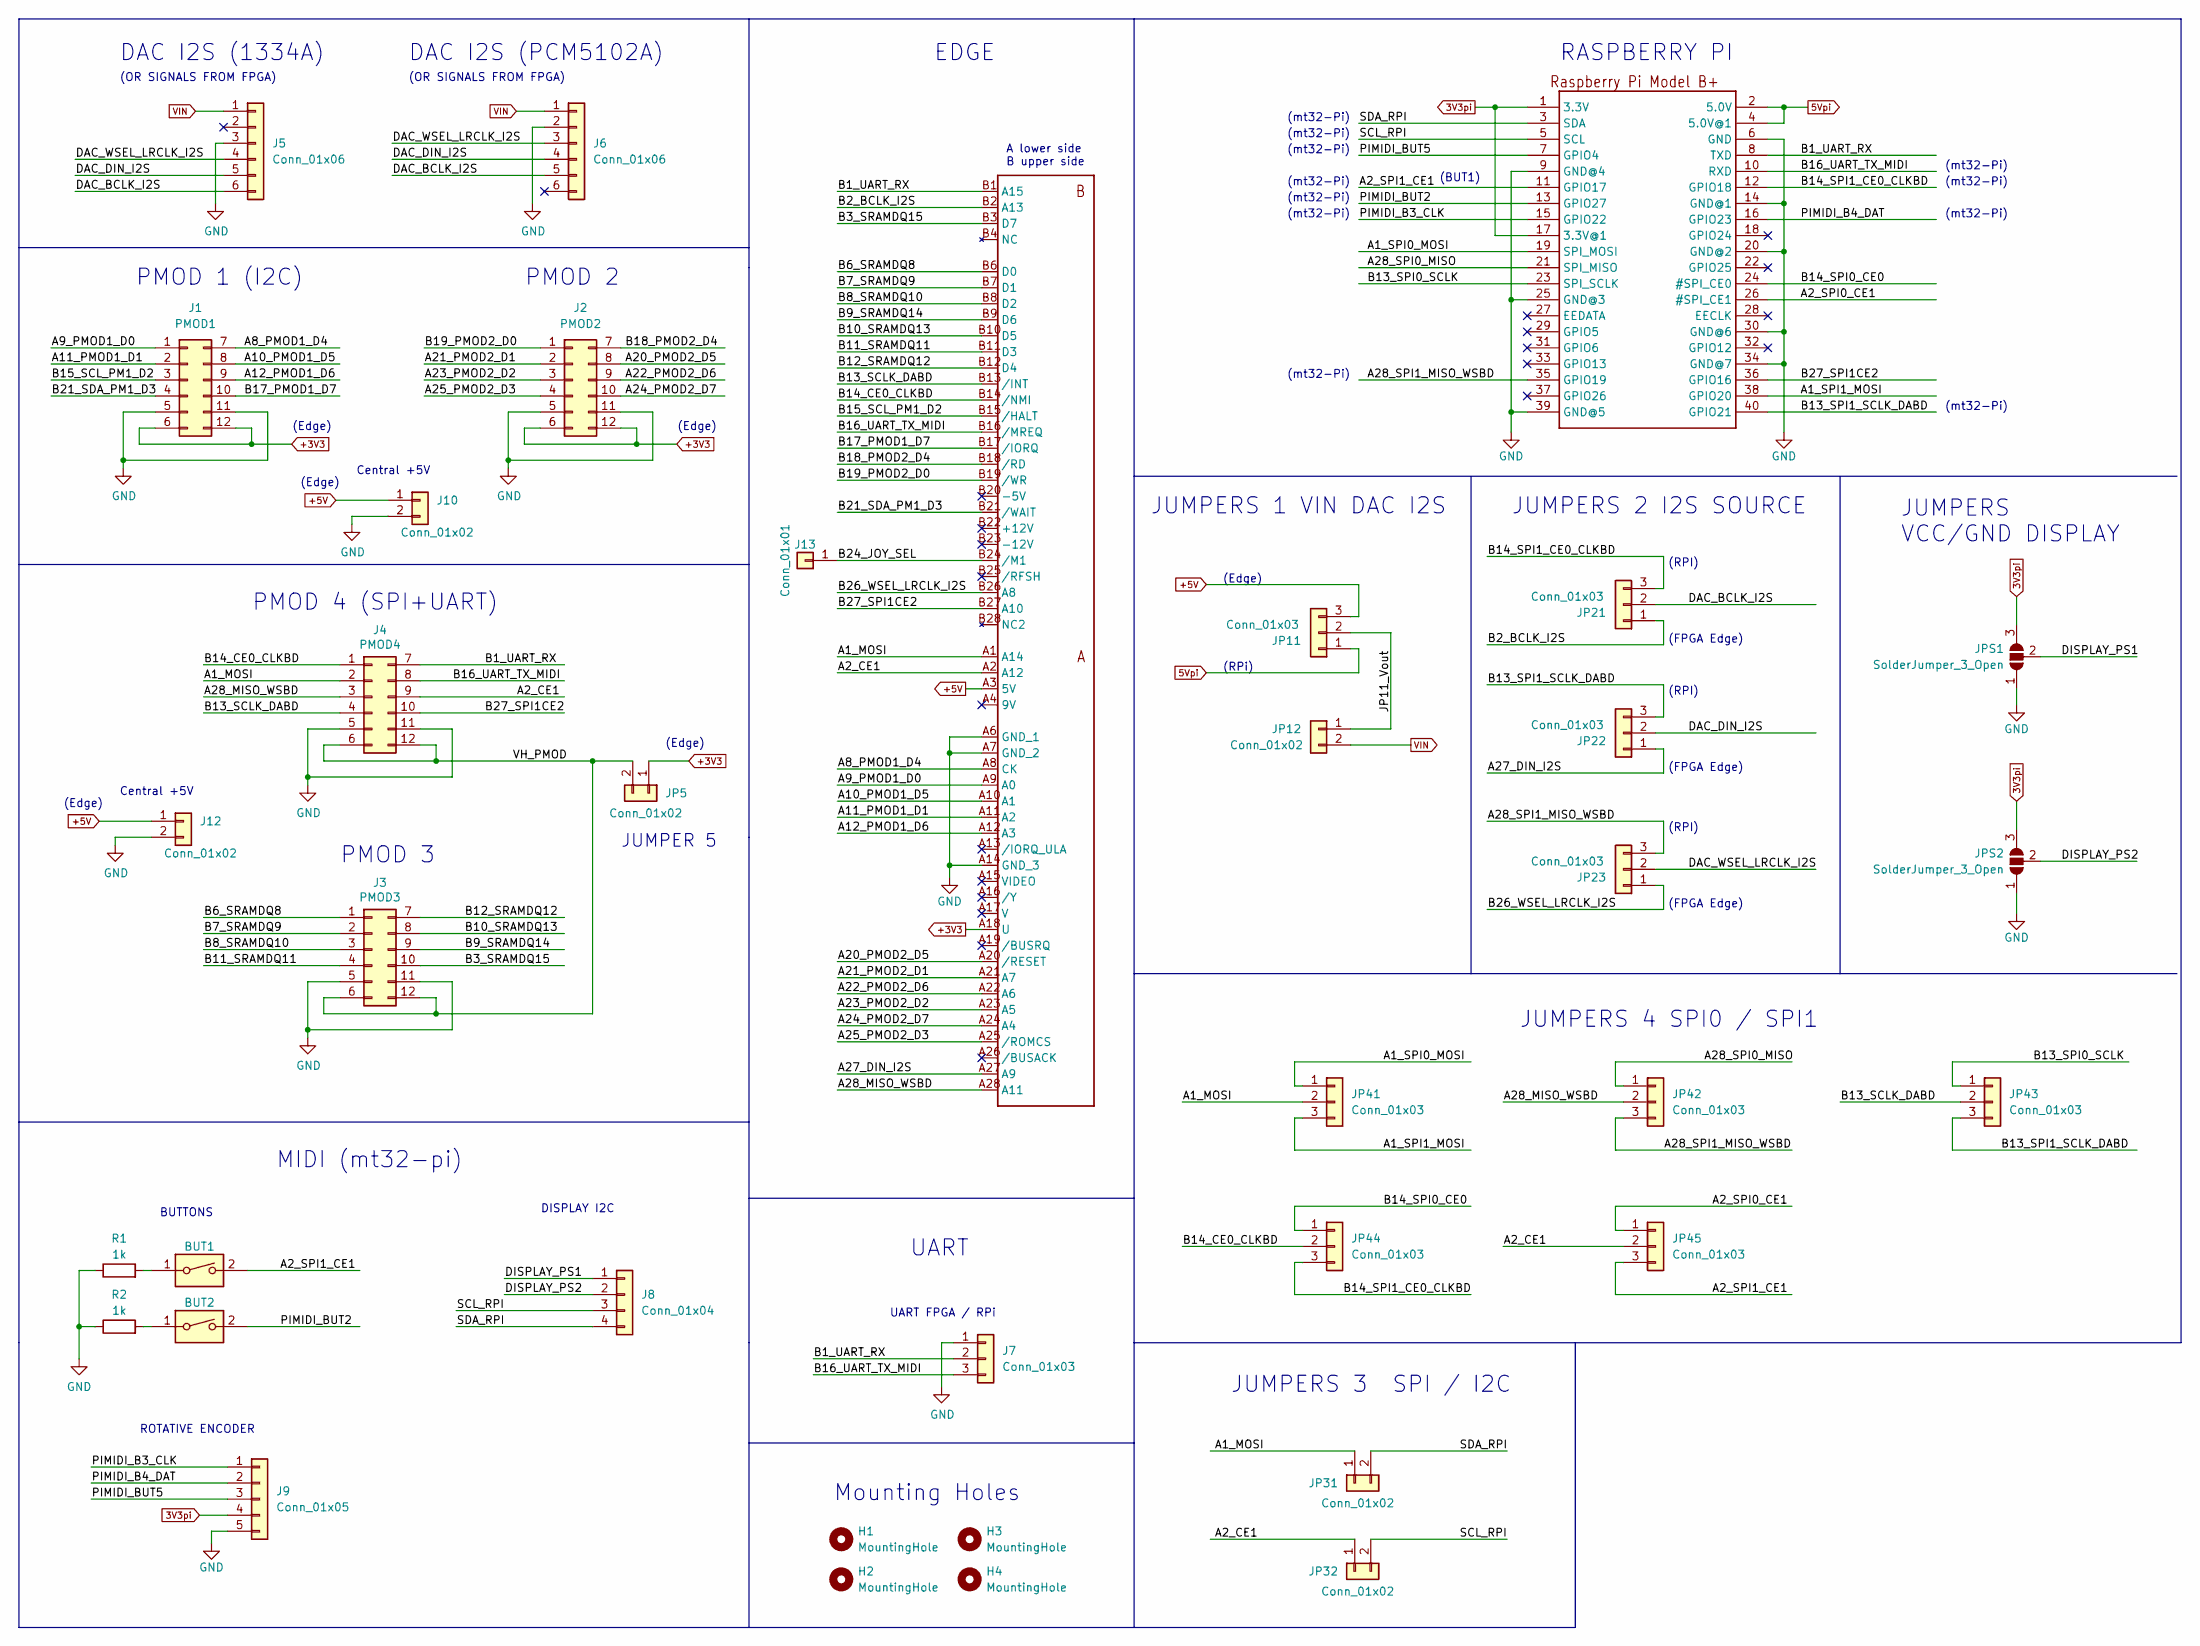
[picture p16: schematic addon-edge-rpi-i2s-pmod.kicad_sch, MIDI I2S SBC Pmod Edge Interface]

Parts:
BUT1, BUT2: SW_DIP_x01; SW_PUSH_6mm_H5mm
EDGE1: ZXSP_ED2X28_SPE_SOL_EDGE; 2X28_SPE2
H1, H2, H3, H4: MountingHole; MountingHole_3.2mm_M3
J1: PMOD1; Pmod_2x06_P2.54mm_Vertical_2
J2: PMOD2; Pmod_2x06_P2.54mm_Vertical_2
J3: PMOD3; PMOD_Female_Horizontal_2
J4: PMOD4; PMOD_Female_Horizontal_2
J5: Conn_01x06; UDA1334
J6: Conn_01x06; PCM5102
J7: Conn_01x03; PinHeader_1x03_P2.54mm_Vertical
J8: Conn_01x04; I2C_DISPLAY_MULTI2
J9: Conn_01x05; PinSocket_1x05_P2.54mm_Vertical
J10: Conn_01x02; PinSocket_1x02_P2.54mm_Vertical
J12: Conn_01x02; PinSocket_2x01_P2.54mm_Horizontal
J13: Conn_01x01; PinHeader_1x01_P2.54mm_Vertical
JP5, JP31, JP32: Conn_01x02; PinHeader_1x02_P2.54mm_Vertical
JP11, JP21, JP22, JP23, JP41, JP42, JP43, JP44, JP45: Conn_01x03; PinHeader_1x03_P2.54mm_Horizontal
JP12: Conn_01x02; PinHeader_1x02_P2.54mm_Horizontal
JPS1, JPS2: SolderJumper_3_Open; SolderJumper-3_P1.3mm_Open_RoundedPad1.0x1.5mm_NumberLabels
R1, R2: 1k; R_1206_3216Metric_Pad1.30x1.75mm_HandSolder
RPI1: RASPBERRYPI_BPLUS_BONNETNODIM; PinSocket_2x20_P2.54mm_Vertical

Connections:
3V3pi: J9.4, JPS1.3 (B), JPS2.3 (B), RPI1.1 (3.3V), RPI1.17 (3.3V@1)
5Vpi: JP11.1, RPI1.2 (5.0V), RPI1.4 (5.0V@1)
+3V3: EDGE1.A18 (U), J1.6, J1.12, J2.6, J2.12, JP5.1
+5V: EDGE1.A3 (5V), J10.1, J12.1, JP11.3
/A1_MOSI: EDGE1.A1 (A14), J4.2, JP31.1, JP41.2
/A1_SPI0_MOSI: JP41.1, RPI1.19 (SPI_MOSI)
/A1_SPI1_MOSI: JP41.3, RPI1.38 (GPIO20)
/A2_CE1: EDGE1.A2 (A12), J4.9, JP32.1, JP45.2
/A2_SPI0_CE1: JP45.1, RPI1.26 (#SPI_CE1)
/A2_SPI1_CE1: BUT1.2, JP45.3, RPI1.11 (GPIO17)
/A8_PMOD1_D4: EDGE1.A8 (CK), J1.7
/A9_PMOD1_D0: EDGE1.A9 (A0), J1.1
/A10_PMOD1_D5: EDGE1.A10 (A1), J1.8
/A11_PMOD1_D1: EDGE1.A11 (A2), J1.2
/A12_PMOD1_D6: EDGE1.A12 (A3), J1.9
/A20_PMOD2_D5: EDGE1.A20 (/RESET), J2.8
/A21_PMOD2_D1: EDGE1.A21 (A7), J2.2
/A22_PMOD2_D6: EDGE1.A22 (A6), J2.9
/A23_PMOD2_D2: EDGE1.A23 (A5), J2.3
/A24_PMOD2_D7: EDGE1.A24 (A4), J2.10
/A25_PMOD2_D3: EDGE1.A25 (/ROMCS), J2.4
/A27_DIN_I2S: EDGE1.A27 (A9), JP22.1
/A28_MISO_WSBD: EDGE1.A28 (A11), J4.3, JP42.2
/A28_SPI0_MISO: JP42.1, RPI1.21 (SPI_MISO)
/A28_SPI1_MISO_WSBD: JP23.3, JP42.3, RPI1.35 (GPIO19)
/B1_UART_RX: EDGE1.B1 (A15), J4.7, J7.2, RPI1.8 (TXD)
/B2_BCLK_I2S: EDGE1.B2 (A13), JP21.1
/B3_SRAMDQ15: EDGE1.B3 (D7), J3.10
/B6_SRAMDQ8: EDGE1.B6 (D0), J3.1
/B7_SRAMDQ9: EDGE1.B7 (D1), J3.2
/B8_SRAMDQ10: EDGE1.B8 (D2), J3.3
/B9_SRAMDQ14: EDGE1.B9 (D6), J3.9
/B10_SRAMDQ13: EDGE1.B10 (D5), J3.8
/B11_SRAMDQ11: EDGE1.B11 (D3), J3.4
/B12_SRAMDQ12: EDGE1.B12 (D4), J3.7
/B13_SCLK_DABD: EDGE1.B13 (/INT), J4.4, JP43.2
/B13_SPI0_SCLK: JP43.1, RPI1.23 (SPI_SCLK)
/B13_SPI1_SCLK_DABD: JP22.3, JP43.3, RPI1.40 (GPIO21)
/B14_CE0_CLKBD: EDGE1.B14 (/NMI), J4.1, JP44.2
/B14_SPI0_CE0: JP44.1, RPI1.24 (#SPI_CE0)
/B14_SPI1_CE0_CLKBD: JP21.3, JP44.3, RPI1.12 (GPIO18)
/B15_SCL_PM1_D2: EDGE1.B15 (/HALT), J1.3
/B16_UART_TX_MIDI: EDGE1.B16 (/MREQ), J4.8, J7.3, RPI1.10 (RXD)
/B17_PMOD1_D7: EDGE1.B17 (/IORQ), J1.10
/B18_PMOD2_D4: EDGE1.B18 (/RD), J2.7
/B19_PMOD2_D0: EDGE1.B19 (/WR), J2.1
/B21_SDA_PM1_D3: EDGE1.B21 (/WAIT), J1.4
/B24_JOY_SEL: EDGE1.B24 (/M1), J13.1
/B26_WSEL_LRCLK_I2S: EDGE1.B26 (A8), JP23.1
/B27_SPI1CE2: EDGE1.B27 (A10), J4.10, RPI1.36 (GPIO16)
/DAC_BCLK_I2S: J5.6, J6.5, JP21.2
/DAC_DIN_I2S: J5.5, J6.4, JP22.2
/DAC_WSEL_LRCLK_I2S: J5.4, J6.3, JP23.2
/DISPLAY_PS1: J8.1, JPS1.2 (C)
/DISPLAY_PS2: J8.2, JPS2.2 (C)
/JP11_Vout: JP11.2, JP12.1
/PIMIDI_B3_CLK: J9.1, RPI1.15 (GPIO22)
/PIMIDI_B4_DAT: J9.2, RPI1.16 (GPIO23)
/PIMIDI_BUT2: BUT2.2, RPI1.13 (GPIO27)
/PIMIDI_BUT5: J9.3, RPI1.7 (GPIO4)
/SCL_RPI: J8.3, JP32.2, RPI1.5 (SCL)
/SDA_RPI: J8.4, JP31.2, RPI1.3 (SDA)
/VH_PMOD: J3.6, J3.12, J4.6, J4.12, JP5.2
GND: EDGE1.A6 (GND_1), EDGE1.A7 (GND_2), EDGE1.A14 (GND_3), J1.5, J1.11, J2.5, J2.11, J3.5, J3.11, J4.5, J4.11, J5.3, J6.2, J7.1, J9.5, J10.2, J12.2, JPS1.1 (A), JPS2.1 (A), R1.1, R2.1, RPI1.6 (GND), RPI1.9 (GND@4), RPI1.14 (GND@1), RPI1.20 (GND@2), RPI1.25 (GND@3), RPI1.30 (GND@6), RPI1.34 (GND@7), RPI1.39 (GND@5)
unnamed: BUT1.1, R1.2
unnamed: BUT2.1, R2.2
VIN: J5.1, J6.1, JP12.2

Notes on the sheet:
JUMPERS 1 VIN DAC I2S
(mt32-Pi)
JUMPERS VCC/GND DISPLAY
PMOD 3
Central +5V
JUMPERS 4 SPI0 / SPI1
(RPI)
JUMPERS 2 I2S SOURCE
(OR SIGNALS FROM FPGA)
PMOD 4 (SPI+UART)
PMOD 1 (I2C)
Mounting Holes
UART FPGA / RPi
DISPLAY I2C
EDGE
(FPGA Edge)
(Edge)
(BUT1)
RASPBERRY PI
JUMPERS 3 SPI / I2C
UART
MIDI (mt32-pi)
JUMPER 5
ROTATIVE ENCODER
BUTTONS
(RPi)
PMOD 2
DAC I2S (1334A)
A lower side B upper side
DAC I2S (PCM5102A)

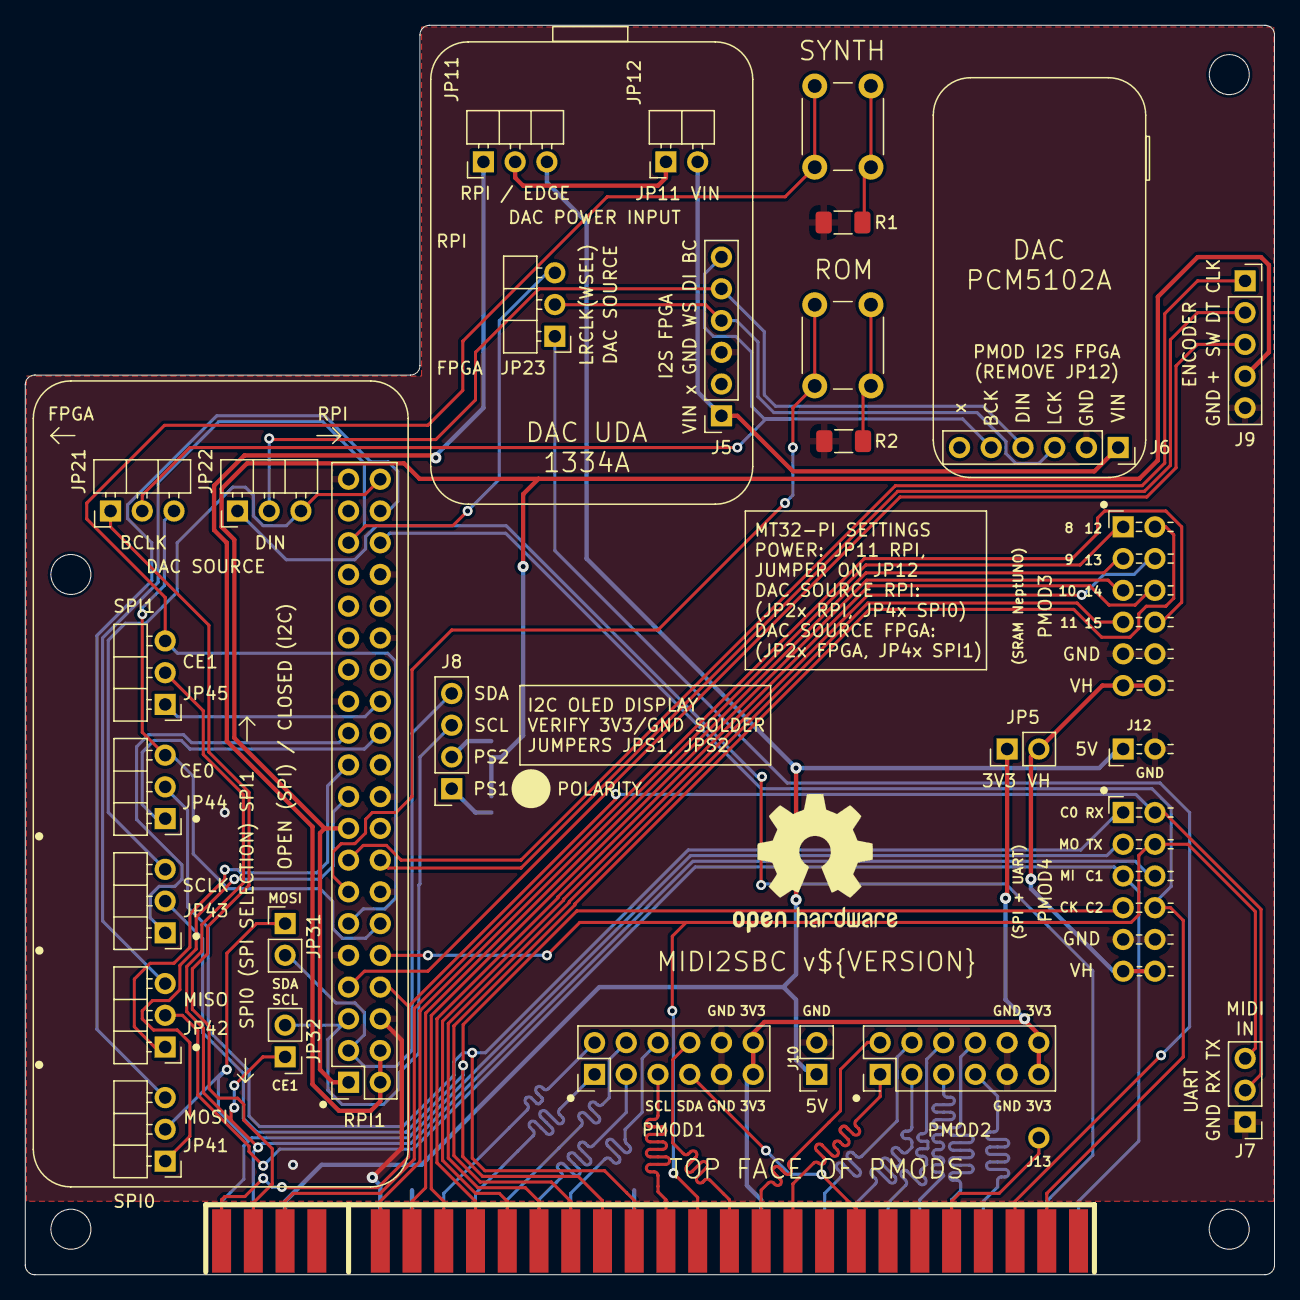
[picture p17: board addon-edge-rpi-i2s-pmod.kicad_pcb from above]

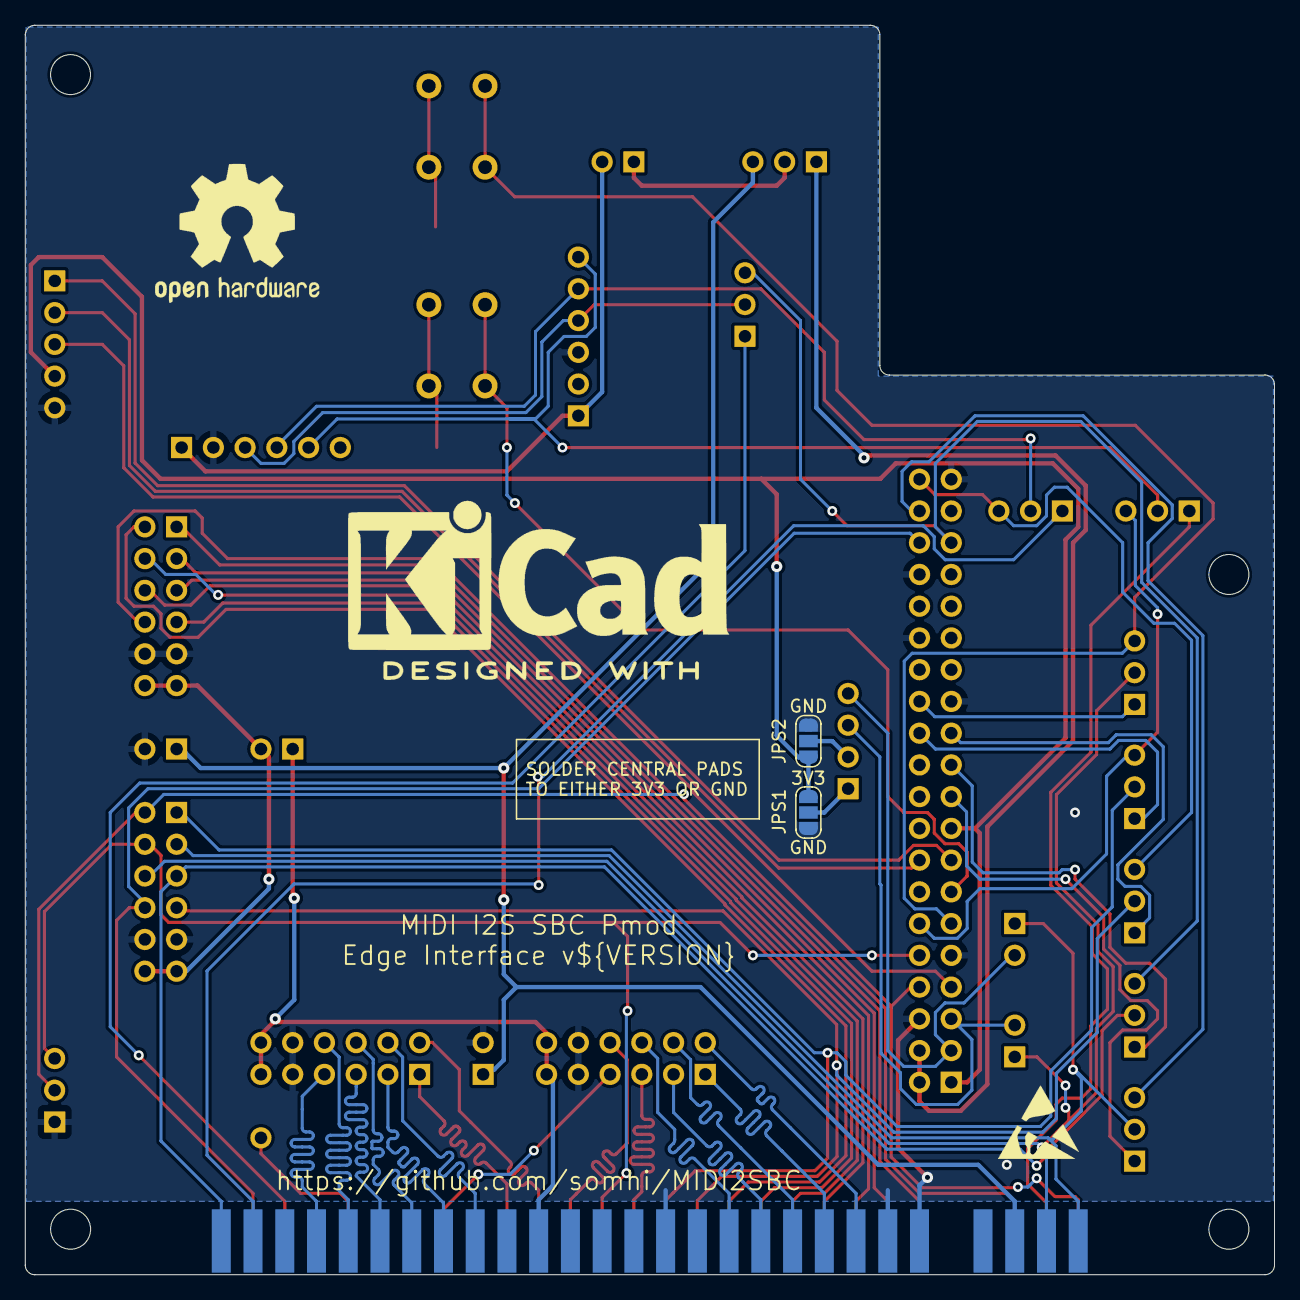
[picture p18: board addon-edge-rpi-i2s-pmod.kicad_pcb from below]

Board: 2 copper layers, 100.0 x 100.0 mm, 41 parts (5 on the bottom side), 67 nets.

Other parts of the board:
LO1: KiCad-Logo2_12mm_SilkScreen
LO2, LO3: OSHW-Logo2_14.6x12mm_SilkScreen
LO4: ESD-Logo_6.6x6mm_SilkScreen

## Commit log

2022-02-09 rev. 0.38
    [addon-edge-rpi-i2s-pmod.dsn, addon-edge-rpi-i2s-pmod.kicad_pcb, addon-edge-rpi-i2s-pmod.kicad_sch]
2022-02-10 update 10/02/22 initial autorouting
    [addon-edge-rpi-i2s-pmod.dsn, addon-edge-rpi-i2s-pmod.kicad_pcb, addon-edge-rpi-i2s-pmod.kicad_sch]
2022-02-12 rev 0.40
    [addon-edge-rpi-i2s-pmod.kicad_pcb, addon-edge-rpi-i2s-pmod.kicad_sch]
2022-02-13 rev. 0.41
    [Pinout_Edge_RPi_i2s_pmod_v0.38.ods, Pinout_Edge_RPi_i2s_pmod_v0.41.ods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]
2022-02-15 modified jumper spacing for allowing switches
    [Pinout_Edge_RPi_i2s_pmod_v0.41.ods, addon-edge-rpi-i2s-pmod.kicad_pcb, addon-edge-rpi-i2s-pmod.kicad_sch]
2022-02-22 v0.50 major changes
    [Pinout_Edge_RPi_i2s_pmod_v0.50.ods, addon-edge-rpi-i2s-pmod.kicad_pcb, addon-edge-rpi-i2s-pmod.kicad_sch]
2022-02-22 flow diagram updated
2022-02-23 v0.51 manual routing finished
    [addon-edge-rpi-i2s-pmod.kicad_pcb]
2022-02-24 v0.52 changed tracks pmod 1 & 2
    [addon-edge-rpi-i2s-pmod.kicad_pcb, addon-edge-rpi-i2s-pmod.kicad_sch]
2022-02-25 generated gerber files
    [addon-edge-rpi-i2s-pmod-B_Cu.gbl, addon-edge-rpi-i2s-pmod-B_Cu.gbr, addon-edge-rpi-i2s-pmod-B_Mask.gbs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]
2022-02-25 v0.6 silkscreen and gerber updated
    [addon-edge-rpi-i2s-pmod-B_Cu.gbl, addon-edge-rpi-i2s-pmod-B_Mask.gbs, addon-edge-rpi-i2s-pmod-B_Paste.gbp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]
2022-02-28 v0.7 sent to manufacturing
    [addon-edge-rpi-i2s-pmod-B_Cu.gbl, addon-edge-rpi-i2s-pmod-B_Mask.gbs, addon-edge-rpi-i2s-pmod-B_Paste.gbp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]
2022-03-13 v0.71 minor disalignment of pmods 1/2
    [addon-edge-rpi-i2s-pmod.kicad_pcb]
2022-03-19 v0.72 silkscreen updated
    [addon-edge-rpi-i2s-pmod.csv, addon-edge-rpi-i2s-pmod.kicad_pcb, addon-edge-rpi-i2s-pmod.ods]
2022-03-20 comments on schematic
    [addon-edge-rpi-i2s-pmod.kicad_sch]
2022-03-24 v1.00 minor changes after testing manufactured v0.7
    [Pinout_Edge_RPi_i2s_pmod_v0.50.ods, Pinout_Edge_RPi_i2s_pmod_v1.00.ods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]
2022-03-25 silkscreen mod from v0.7 to v1.0
2022-03-28 v1.01 pmod i2s
    [addon-edge-rpi-i2s-pmod-B_Cu.gbl, addon-edge-rpi-i2s-pmod-B_Mask.gbs, addon-edge-rpi-i2s-pmod-B_Paste.gbp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]
2022-04-09 v1.02 minor silkscreen updates
    [addon-edge-rpi-i2s-pmod.kicad_pcb]
2022-11-22 v1.05 minor silkscreen changes
    [addon-edge-rpi-i2s-pmod.kicad_pcb]
2022-11-22 changed repository name
    [addon-edge-rpi-i2s-pmod.kicad_sch]
2022-11-22 v1.10 added i2c jumpers to control mt32-pi from fpga
    [addon-edge-rpi-i2s-pmod.kicad_pcb, addon-edge-rpi-i2s-pmod.kicad_sch]
2022-12-26 v.1.10 generated gerber files for production
    [addon-edge-rpi-i2s-pmod-B_Cu.gbl, addon-edge-rpi-i2s-pmod-B_Mask.gbs, addon-edge-rpi-i2s-pmod-B_Paste.gbp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]
2023-01-31 updated .ods BOM with purchase links
    [addon-edge-rpi-i2s-pmod.ods]
